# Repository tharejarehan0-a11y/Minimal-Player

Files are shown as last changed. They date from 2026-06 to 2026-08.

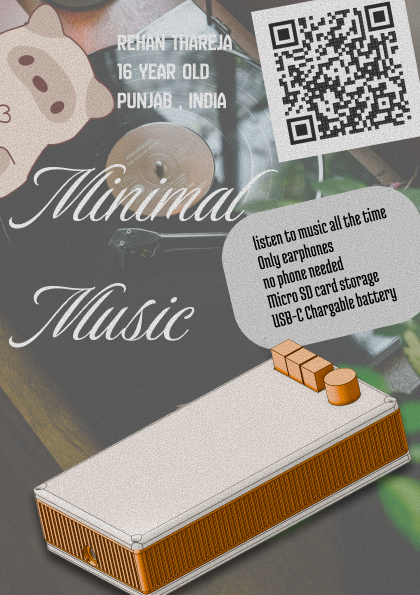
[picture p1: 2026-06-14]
A5 - 2.png

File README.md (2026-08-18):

# Minimal Player

**All the recordings are in JOURNAL.MD**

<p align="center">
A5 - 2
</p>
Minimal player is a device i can use to listen music in a compact way with only wired earphones offline and without worrying too much about the battery as it has a long battery life

---

## Why I Created This

The inspiration was from the need of having something i can carry everyday with me and listen music from with looking asthetic at the same times and some device with which i can use my wired earphones. But the thing is that i like to use such a device that gives only audio output through the audio jack bcz when you unplug it . It suddenly starts to play and doesnt stop i like that env where i can listen to music and no one disturbs me that is who i am and who i always will be . So i though why not create an Mp3 player where it has cool aesthetic design and also fulfills my requirements so i started with a simple pcb and then i came upon dac onto that and the battery mangagement we will talk more about that later . but for now i then did the routing and created the case the case was also quite complicated which we will cover on how to create that in aa nutshell in the next segment.

---

## How to create the MP3 schematics

I started by taking the raspberry pi pico cause it is the most easiest to work with microboard and also one of the most powerful ones also one more thing that attracted me about it was that it is micropython based which made the mechanics of code really easy for me to be done in the board itself. Then i came up with the decoupling of it and a switch for booting and stuff and then i stranded upon the micro sd slot the micro slot was a great option because it is one of the easiest to work with and works with the UART protocol which makes the wirinig also quite easy . Then i came upto the question okay i stored the data i have a microboard but what will i do of js the data the data also needs to play and what will play that that is the DAC and then i added the DAC to the MP3 Player which was quite complicated tho but still i added that and . It was a very difficult task to choose the right one for me , I Chose the PCM5102A for this and did stuff . I then continued to add the audio jack to it because the signals need to convert to sound somehow and i need my quite env after that i continued with working with the battery management and added the batter connector and the usb c for charging i also added the voltage regulator for stuff that requires 3.3v and 5v and handeled both separately and then i added some switches and lights for basic controls and also basic checks and then i chose to start with the rotatory encoders for more controls and then i switched to the pcb

---

## PCB

The pcb was quite complicated tho ngl I had to take care that the digital and analog signals do not interfare each other and also i have to take care of the thickness of the routing at different position due to the power management system itself and different power requiremwents here and there and then i went onto vias and stuff and it was quite a fast task tho 

---

## Case

Then i went onto the case and stuff . I wanted a quite aesthetic case tbh but at the same time I also wanted a case that fits my requirements like to be minimal and to signify that i am in my zone but still cool so i went with the orange and white color theme i know sounds a bit off but seems to fit my thingy and then what i did was i added little engravings at the sides of the case and added rotatory encoders to it i added two of them because i wanted to control the audio with one whereas the soong qeue with the other was quite a complicated task to add and make the cover for the rotatory encoders.

---

## Bill of Materials (BOM)

The table below lists all components used in the Minimal Player, matching the exact footprints and values from the KiCad PCB design layout. 

| Designator | Value | Footprint | Qty | India Sourcing / Purchase Links |
| :--- | :--- | :--- | :--- | :--- |
| **A1** | RaspberryPi_Pico | RaspberryPi_Pico_Common_THT | 1 | [Robu.in - Raspberry Pi Pico](https://robu.in/product/raspberry-pi-pico/) |
| **BT1** | Battery Connector | JST_PH_B2B-PH-K_1x02_P2.00mm_Vertical | 1 | [Robu.in - JST PH 2.0mm Male Header](https://robu.in/product/jst-ph-2-0-2-pin-male-connector-straight/) |
| **C1, C10, C11, C14, C15, C3** | $10\,\mu\text{F}$ | 0805 SMD Capacitor | 6 | [ElectronicsComp - 10uF 0805 Ceramic](https://www.electronicscomp.com/10uf-25v-0805-smd-capacitor) |
| **C12** | $2.2\text{ nF}$ | 0805 SMD Capacitor | 1 | [ElectronicsComp - 2.2nF 0805 Ceramic](https://www.electronicscomp.com/2.2nf-50v-0805-smd-capacitor) |
| **C13, R13** | 470 *(See Notes)* | 0805 SMD | 2 | [Resistor (470 $\Omega$)](https://www.electronicscomp.com/470-ohm-0805-smd-resistor) / [Capacitor (470 pF)](https://www.electronicscomp.com/470pf-50v-0805-smd-capacitor) |
| **C2, C5, C6, C8, C9** | $0.1\,\mu\text{F}$ | 0805 SMD Capacitor | 5 | [ElectronicsComp - 0.1uF 0805 Ceramic](https://www.electronicscomp.com/0.1uf-50v-0805-smd-capacitor) |
| **C4, C7** | $2.2\,\mu\text{F}$ | 0805 SMD Capacitor | 2 | [ElectronicsComp - 2.2uF 0805 Ceramic](https://www.electronicscomp.com/2.2uf-50v-0805-smd-capacitor) |
| **D1, D2** | LED_Small | 0805 SMD LED | 2 | [Robu.in - 0805 SMD LED Kit](https://robu.in/product/0805-smd-led-diode-assortment-kit-5-colors/) |
| **J1** | USB_C_Receptacle_14P | USB_C_Receptacle_HRO_TYPE-C-31-M-12 | 1 | [Robu.in - TYPE-C-31-M-12 Compatible 16P SMT](https://robu.in/product/usb-c-type-c-female-connector-16-pin-surface-mount/) |
| **J2** | Micro_SD_Card Slot | microSD_HC_Molex_104031-0811 | 1 | [ElectronicsComp - Push-Push MicroSD Slot](https://www.electronicscomp.com/micro-sd-card-slot-socket-smd-push-push-type) / [DigiKey India - Molex Exact](https://www.digikey.in/en/products/detail/molex/1040310811/3044122) |
| **J3** | AudioJack3 | Jack_3.5mm_CUI_SJ1-3523N_Horizontal | 1 | [DigiKey India - CUI SJ1-3523N Exact](https://www.digikey.in/en/products/detail/cui-devices/SJ1-3523N/738686) |
| **R1, R11, R2** | $5.1\text{ k}\Omega$ | 0805 SMD Resistor | 3 | [ElectronicsComp - 5.1k 0805 Resistor](https://www.electronicscomp.com/5.1k-ohm-0805-smd-resistor) |
| **R10** | $1.2\text{ k}\Omega$ | 0805 SMD Resistor | 1 | [ElectronicsComp - 1.2k 0805 Resistor](https://www.electronicscomp.com/1.2k-ohm-0805-smd-resistor) |
| **R12, R14, R5, R6, R7, R8, TH1** | $10\text{ k}\Omega$ *(See Notes)* | 0805 SMD | 7 | [Resistor (10k $\Omega$)](https://www.electronicscomp.com/10k-ohm-0805-smd-resistor) / [NTC Thermistor](https://www.electronicscomp.com/10k-ntc-thermistor-smd-0805) |
| **R3, R4** | $1\text{ k}\Omega$ | 0805 SMD Resistor | 2 | [ElectronicsComp - 1k 0805 Resistor](https://www.electronicscomp.com/1k-ohm-0805-smd-resistor) |
| **R9** | 0.4 / 400 $\Omega$ | 0805 SMD Resistor | 1 | [ElectronicsComp - 0805 SMD Resistor Assortment](https://www.electronicscomp.com/0805-smd-resistor-kit-36-values) |
| **SW1, SW2, SW3, SW4** | SW_SPST | SW_PUSH_6mm_H4.3mm | 4 | [Robu.in - 6x6x4.3mm Tactile Switch](https://robu.in/product/6x6x4-3mm-tactile-micro-push-button-switch-2-pin/) |
| **SW5** | RotaryEncoder | RotaryEncoder_Bourns_Vertical_PEC12R | 1 | [ElectronicsComp - EC11/12 with Switch](https://www.electronicscomp.com/ec11-rotary-encoder-with-switch-20mm-half-shaft) / [DigiKey India - Bourns Exact](https://www.digikey.in/en/products/detail/bourns-inc/PEC12R-4220F-S0024/3780188) |
| **U1** | TP4056-42-ESOP8 | SOIC-8-1EP (Exposed Thermal Pad) | 1 | [ElectronicsComp - TP4056 IC](https://www.electronicscomp.com/tp4056-linear-li-ion-battery-charger-ic) |
| **U2** | PCM5102A | TSSOP-20_4.4x6.5mm_P0.65mm | 1 | [ElectronicsComp - PCM5102A IC](https://www.electronicscomp.com/pcm5102a-audio-dac-ic-tssop-20) / [DigiKey India - TI Original](https://www.digikey.in/en/products/detail/texas-instruments/PCM5102APWR/3055979) |

---

# Schematics with Picture

Screenshot 2026-06-15 at 12 40 12 PM

The schematics were not that difficult because both the newer components had the datasheets to be followed the TP4056A and the PAM DAC they were easy to setup but the newer things that i explored onto this project were the electrolytic capcitors and how they have more capacitors and i also learned about this like analog and digital signals are different but sometimes when you have a project where you are going whith a pcb design for only 2 layers you can have same ground for both of them so i had the same ground for both of them and the TP4056 helped a lot with having a stable current towards the pico so that it can run easily and at last the PAM is a machine when it comes to audio only via headphones and works with the 3 pin audio jack that i setted up. I also added rotatory encoder , the buttons and a micro sd card a usb c and a lithium battery which can be recharged 

<br>

# PCB with picture
Screenshot 2026-06-15 at 12 54 30 PM

Then I started with the PCB it was really the hard part to deal with. I started by placing all the components but there were like so many capacitors and resistors that were to be placed which made it so confusing to set it up . So I took the schematics as the reference and placed all the capacitors as it was in that and then I started with routing it and got to know that the traces with the power are to be kept thick and the digital can be thin so i did it all wrong at the first try but got it on the second try. Then was the time to fix the errors . I had like so many errors I had to deal with so i started with the short errors all the way to body malformed errors and stuff and did that at last by filling the zone with AGND as the net 

<br>

# CAD with picture
Screenshot 2026-06-15 at 12 53 39 PM
Onshape is the best . I started by drawing two rectangles and then i extruded the part that was common to only one bigger rectangle in which with the same center was the other rectange and then i extruded it then i made the sketched for those tiny rectangular holes onto the sides of it and with the help of linear pattern i redrew them all easily and then i removed them from the sides to a certain extent to give a retro vibe then i imported the step file for the pcb and then what I did was i made the lower case and the upper case derived some parts and sketches drew the rotatory encoder the buttons . Imported the step files for the springs and the battery and then made the assembly that was it in all 
Onshape link : https://cad.onshape.com/documents/f82830b6c3d912c29ecf4908/w/00f5a3130b75aa3be964c3b3/e/6c625d5a5e73e1ecfabf8af3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

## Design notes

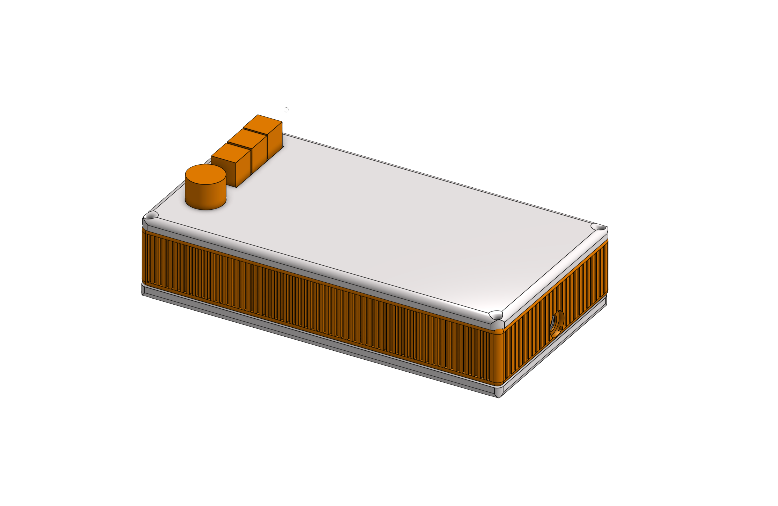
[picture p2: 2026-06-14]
Media/Untitled - 15 June 2026 at 00.29.48.png

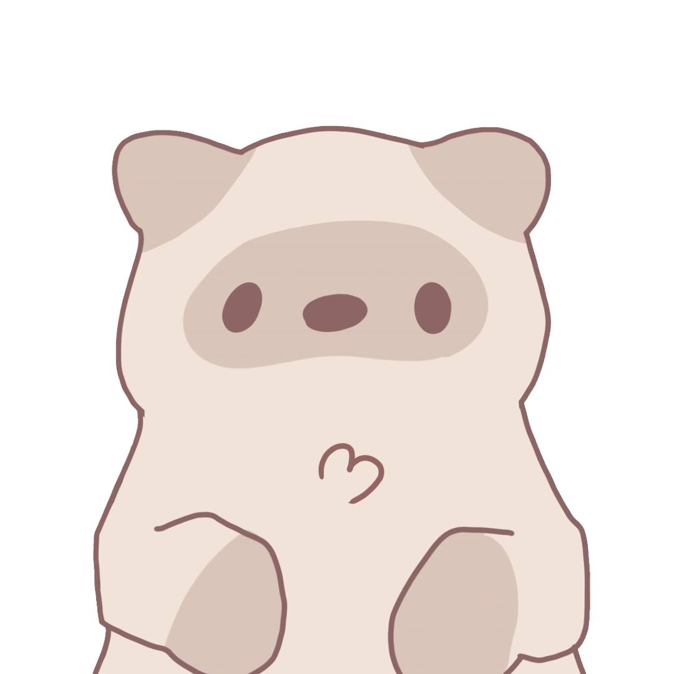
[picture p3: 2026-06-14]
Media/Untitled - 15 June 2026 at 01.00.05.png

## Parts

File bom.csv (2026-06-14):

Designator | Footprint | Quantity | Value | LCSC Part #
A1 | RaspberryPi_Pico_Common_THT | 1 | RaspberryPi_Pico
BT1 | JST_PH_B2B-PH-K_1x02_P2.00mm_Vertical | 1 | Battery
C1, C10, C11, C14, C15, C3 | 0805 | 6 | 10uf
C12 | 0805 | 1 | 2.2nf
C13, R13 | 0805 | 2 | 470
C2, C5, C6, C8, C9 | 0805 | 5 | 0.1uf
C4, C7 | 0805 | 2 | 2.2uf
D1, D2 | 0805 | 2 | LED_Small
J1 | USB_C_Receptacle_HRO_TYPE-C-31-M-12 | 1 | USB_C_Receptacle_USB2.0_14P
J2 | microSD_HC_Molex_104031-0811 | 1 | Micro_SD_Card
J3 | Jack_3.5mm_CUI_SJ1-3523N_Horizontal | 1 | AudioJack3
R1, R11, R2 | 0805 | 3 | 5.1k
R10 | 0805 | 1 | 1.2k
R12, R14, R5, R6, R7, R8, TH1 | 0805 | 7 | 10k
R3, R4 | 0805 | 2 | 1k
R9 | 0805 | 1 | 0.4
SW1, SW2, SW3, SW4 | SW_PUSH_6mm_H4.3mm | 4 | SW_SPST
SW5 | RotaryEncoder_Bourns_Vertical_PEC12R-3x17F-Nxxxx | 1 | RotaryEncoder
U1 | SOIC-8-1EP_3.9x4.9mm_P1.27mm_EP2.41x3.3mm_ThermalVias | 1 | TP4056-42-ESOP8
U2 | TSSOP-20_4.4x6.5mm_P0.65mm | 1 | PCM5102A

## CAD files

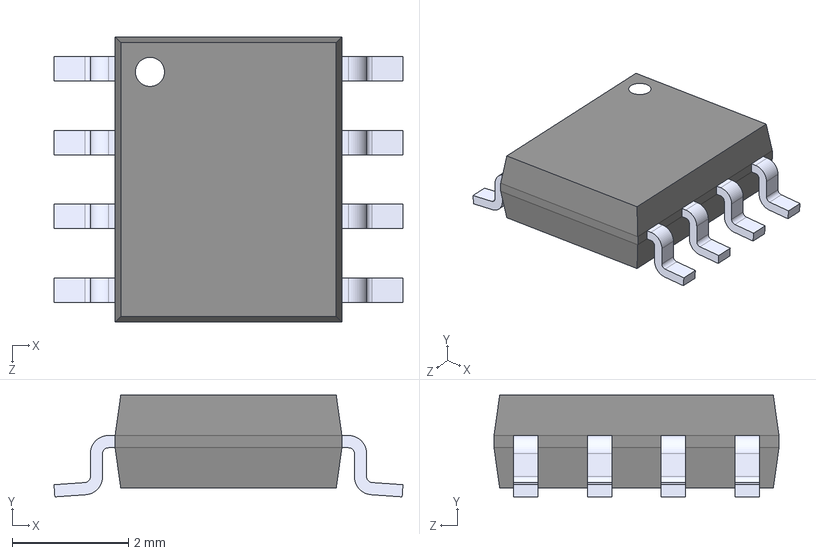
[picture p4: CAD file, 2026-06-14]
3d_models/TP4056-42-ESOP8--3DModel-STEP-56544.STEP
6.00 x 1.75 x 4.90 mm

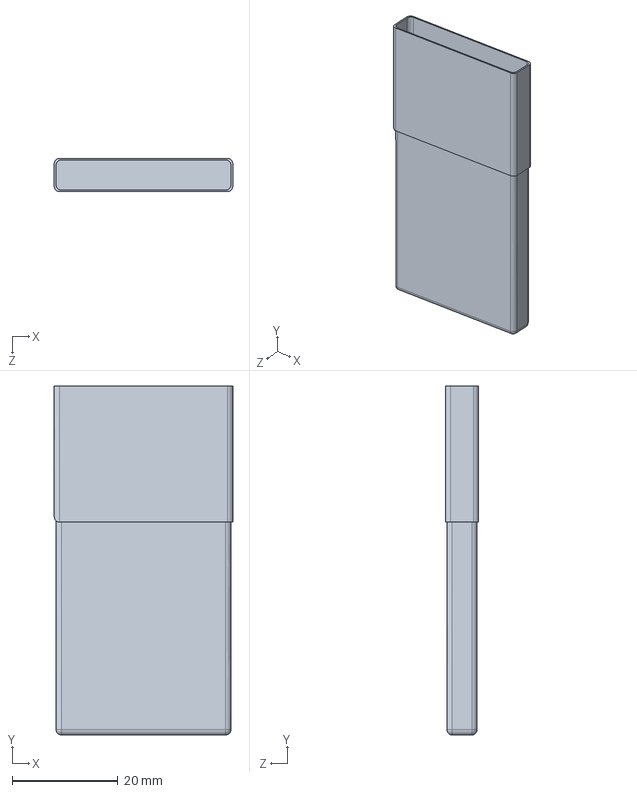
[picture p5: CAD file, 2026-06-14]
3d_models/battery.SLDPRT
33.7 x 65.8 x 6.29 mm

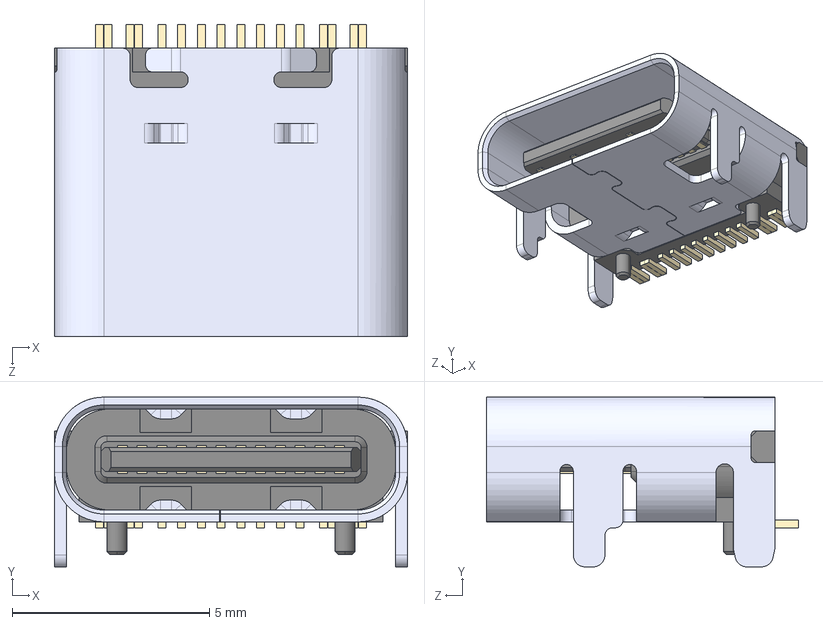
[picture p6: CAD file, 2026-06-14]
3d_models/TYPE-C-31-M-12--3DModel-STEP-56544.STEP
8.94 x 4.30 x 7.90 mm

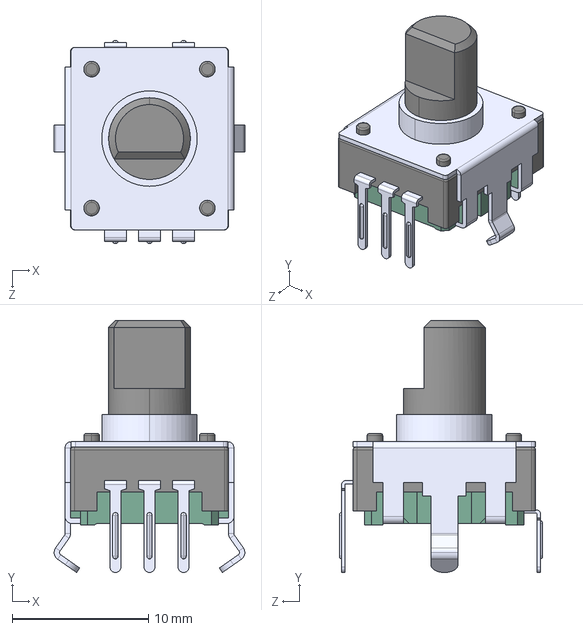
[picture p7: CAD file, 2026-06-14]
3d_models/PEC12R-4115F-S0012--3DModel-STEP-510211.STEP
14.0 x 18.5 x 14.9 mm

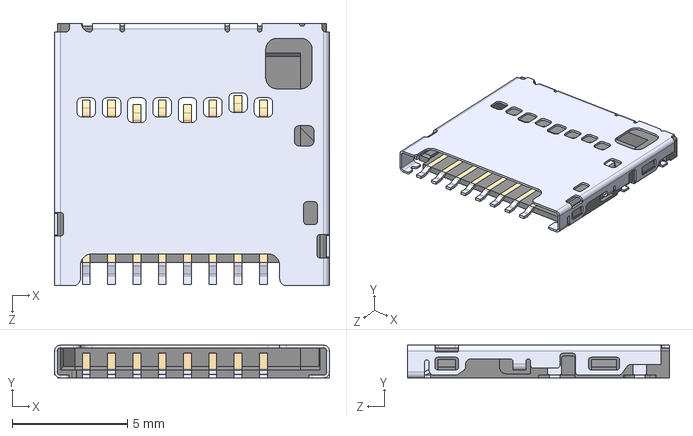
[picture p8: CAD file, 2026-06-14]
3d_models/104031-0811--3DModel-STEP-269445.STEP
12.0 x 1.42 x 11.4 mm

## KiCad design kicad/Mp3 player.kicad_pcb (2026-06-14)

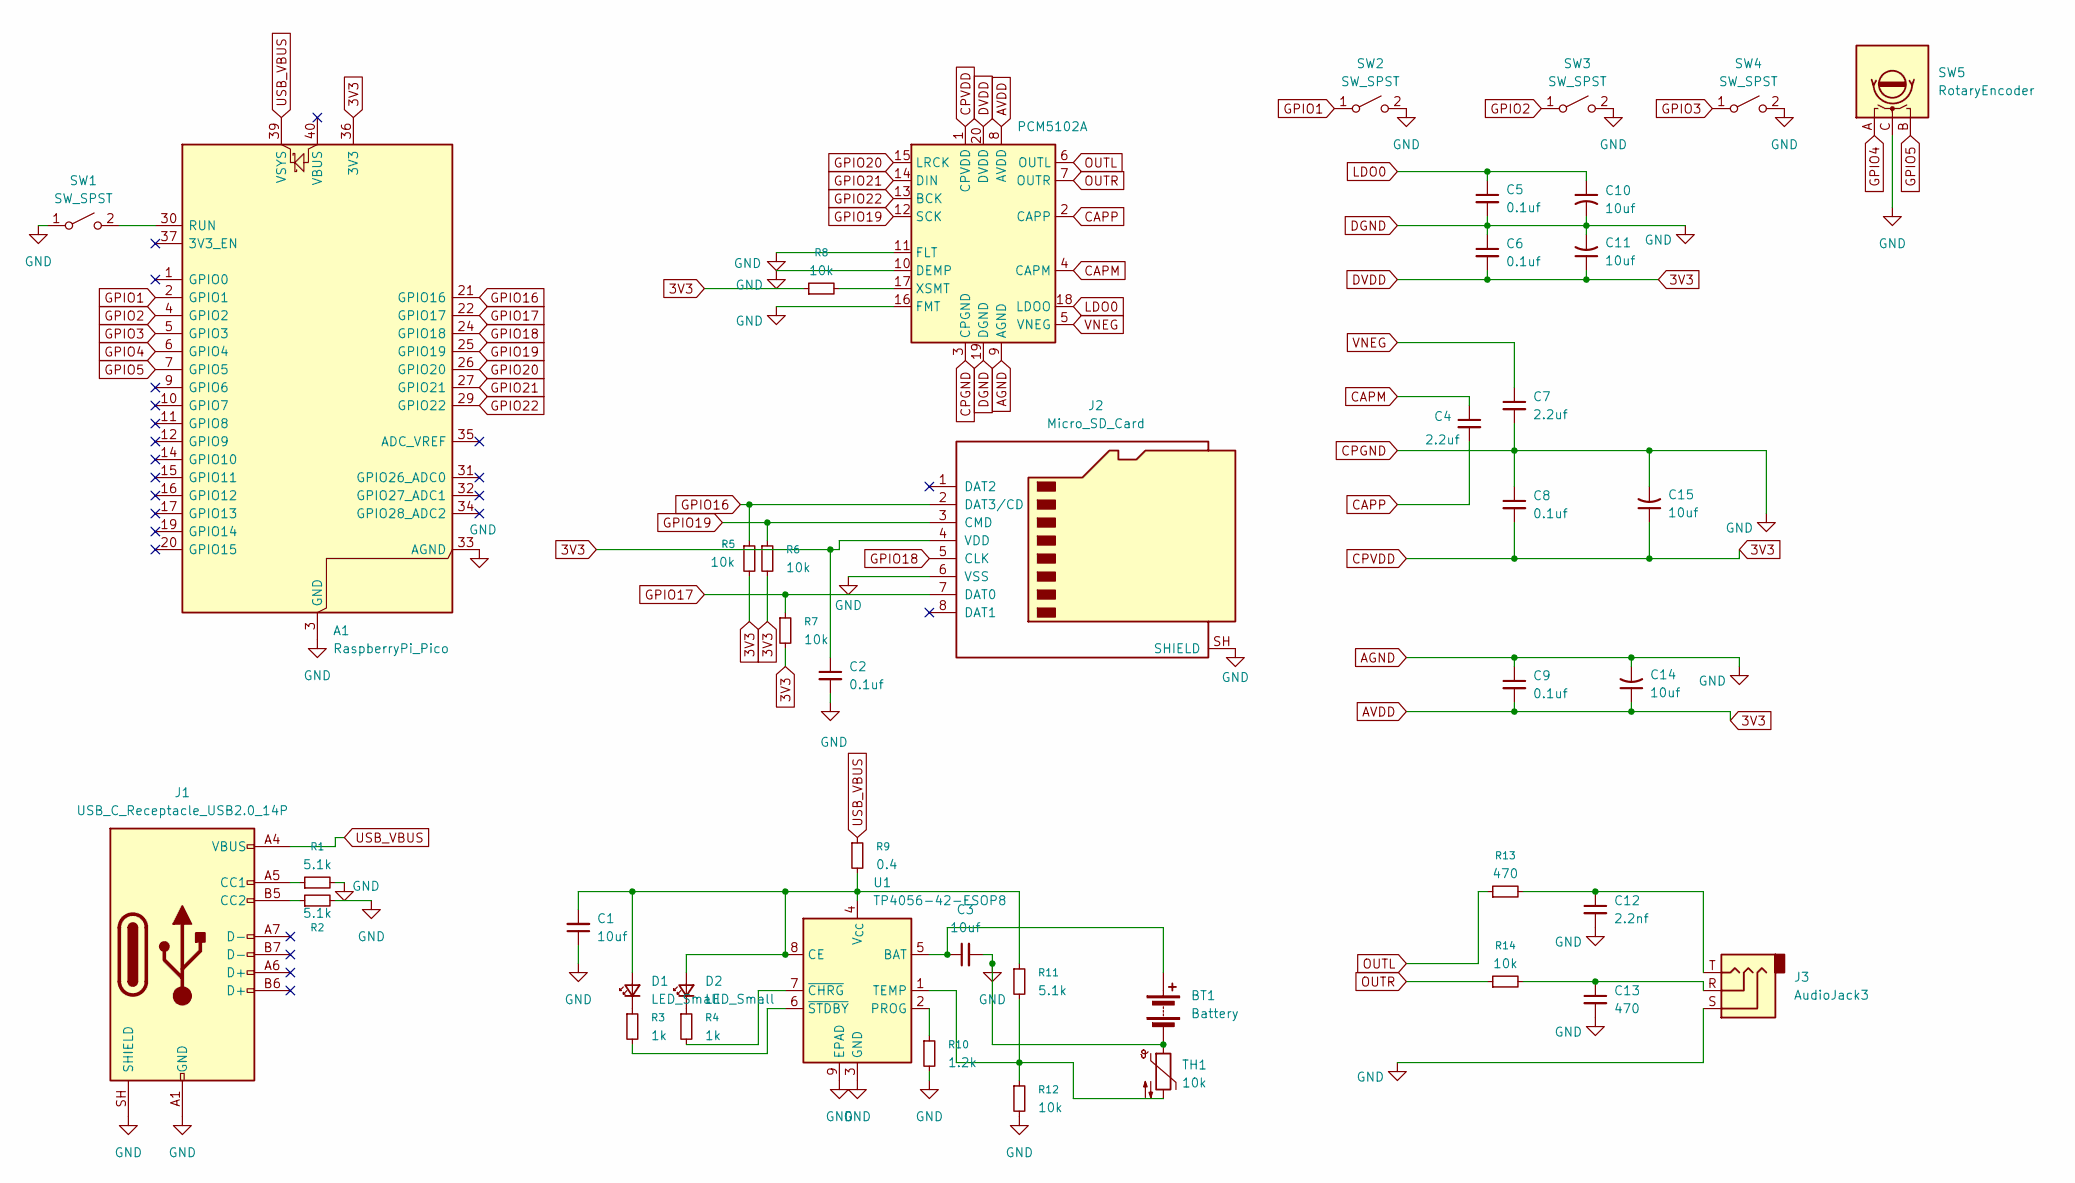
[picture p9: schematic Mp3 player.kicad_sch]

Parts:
A1: RaspberryPi_Pico; RaspberryPi_Pico_Common_THT
BT1: Battery; JST_PH_B2B-PH-K_1x02_P2.00mm_Vertical
C1, C3, C10, C11, C14, C15: 10uf; C_0805_2012Metric
C2, C5, C6, C8, C9: 0.1uf; C_0805_2012Metric
C4, C7: 2.2uf; C_0805_2012Metric
C12: 2.2nf; C_0805_2012Metric_Pad1.18x1.45mm_HandSolder
C13: 470; R_0805_2012Metric
D1, D2: LED_Small; LED_0805_2012Metric
J1: USB_C_Receptacle_USB2.0_14P; USB_C_Receptacle_HRO_TYPE-C-31-M-12
J2: Micro_SD_Card; microSD_HC_Molex_104031-0811
J3: AudioJack3; Jack_3.5mm_CUI_SJ1-3523N_Horizontal
R1, R2, R11: 5.1k; R_0805_2012Metric
R3, R4: 1k; R_0805_2012Metric
R5, R6, R7, R8, R12, R14: 10k; R_0805_2012Metric
R9: 0.4; R_0805_2012Metric
R10: 1.2k; R_0805_2012Metric
R13: 470; R_0805_2012Metric
SW1, SW2, SW3, SW4: SW_SPST; SW_PUSH_6mm_H4.3mm
SW5: RotaryEncoder; RotaryEncoder_Bourns_Vertical_PEC12R-3x17F-Nxxxx
TH1: 10k; R_0805_2012Metric
U1: TP4056-42-ESOP8; SOIC-8-1EP_3.9x4.9mm_P1.27mm_EP2.41x3.3mm_ThermalVias
U2: PCM5102A; TSSOP-20_4.4x6.5mm_P0.65mm

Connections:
3V3: A1.36 (3V3), C2.1, C6.2, C8.2, C9.2, C11.1, C14.1, C15.1, J2.4 (VDD), R5.2, R6.2, R7.2, R8.1, U2.1 (CPVDD), U2.8 (AVDD), U2.20 (DVDD)
AGND: A1.3 (GND), A1.8 (GND), A1.13 (GND), A1.18 (GND), A1.23 (GND), A1.28 (GND), A1.33 (AGND), A1.38 (GND), BT1.2 (-), C1.1, C2.2, C3.2, C5.2, C6.1, C7.2, C8.1, C9.1, C10.2, C11.2, C12.2, C13.2, C14.2, C15.2, J1.A1 (GND), J1.A12 (GND), J1.B1 (GND), J1.B12 (GND), J1.SH (SHIELD), J2.6 (VSS), J2.SH (SHIELD), J3.S, R1.2, R2.2, R10.2, R12.2, SW1.1 (A), SW2.2 (B), SW3.2 (B), SW4.2 (B), SW5.C, TH1.1, U1.3 (GND), U1.9 (EPAD), U2.3 (CPGND), U2.9 (AGND), U2.10 (DEMP), U2.11 (FLT), U2.16 (FMT), U2.19 (DGND)
CAPM: C4.1, U2.4 (CAPM)
CAPP: C4.2, U2.2 (CAPP)
GPIO1: A1.2 (GPIO1), SW2.1 (A)
GPIO2: A1.4 (GPIO2), SW3.1 (A)
GPIO3: A1.5 (GPIO3), SW4.1 (A)
GPIO4: A1.6 (GPIO4), SW5.A
GPIO5: A1.7 (GPIO5), SW5.B
GPIO16: A1.21 (GPIO16), J2.2 (DAT3/CD), R5.1
GPIO17: A1.22 (GPIO17), J2.7 (DAT0), R7.1
GPIO18: A1.24 (GPIO18), J2.5 (CLK)
GPIO19: A1.25 (GPIO19), J2.3 (CMD), R6.1, U2.12 (SCK)
GPIO20: A1.26 (GPIO20), U2.15 (LRCK)
GPIO21: A1.27 (GPIO21), U2.14 (DIN)
GPIO22: A1.29 (GPIO22), U2.13 (BCK)
LDO0: C5.1, C10.1, U2.18 (LDOO)
unnamed: A1.30 (RUN), SW1.2 (B)
unnamed: BT1.1 (+), C3.1, U1.5 (BAT)
unnamed: C12.1, J3.T, R13.2
unnamed: C13.1, J3.R, R14.2
unnamed: C1.2, D1.2 (A), D2.2 (A), R9.2, R11.1, U1.4 (V_{CC}), U1.8 (CE)
unnamed: D1.1 (K), R3.1
unnamed: D2.1 (K), R4.1
unnamed: J1.A5 (CC1), R1.1
unnamed: J1.B5 (CC2), R2.1
unnamed: R10.1, U1.2 (PROG)
unnamed: R11.2, R12.1, TH1.2, U1.1 (TEMP)
unnamed: R4.2, U1.7 (~CHRG)
unnamed: R3.2, U1.6 (~STDBY)
unnamed: R8.2, U2.17 (XSMT)
OUTL: R13.1, U2.6 (OUTL)
OUTR: R14.1, U2.7 (OUTR)
USB_VBUS: A1.39 (VSYS), J1.A4 (VBUS), J1.A9 (VBUS), J1.B4 (VBUS), J1.B9 (VBUS), R9.1
VNEG: C7.1, U2.5 (VNEG)

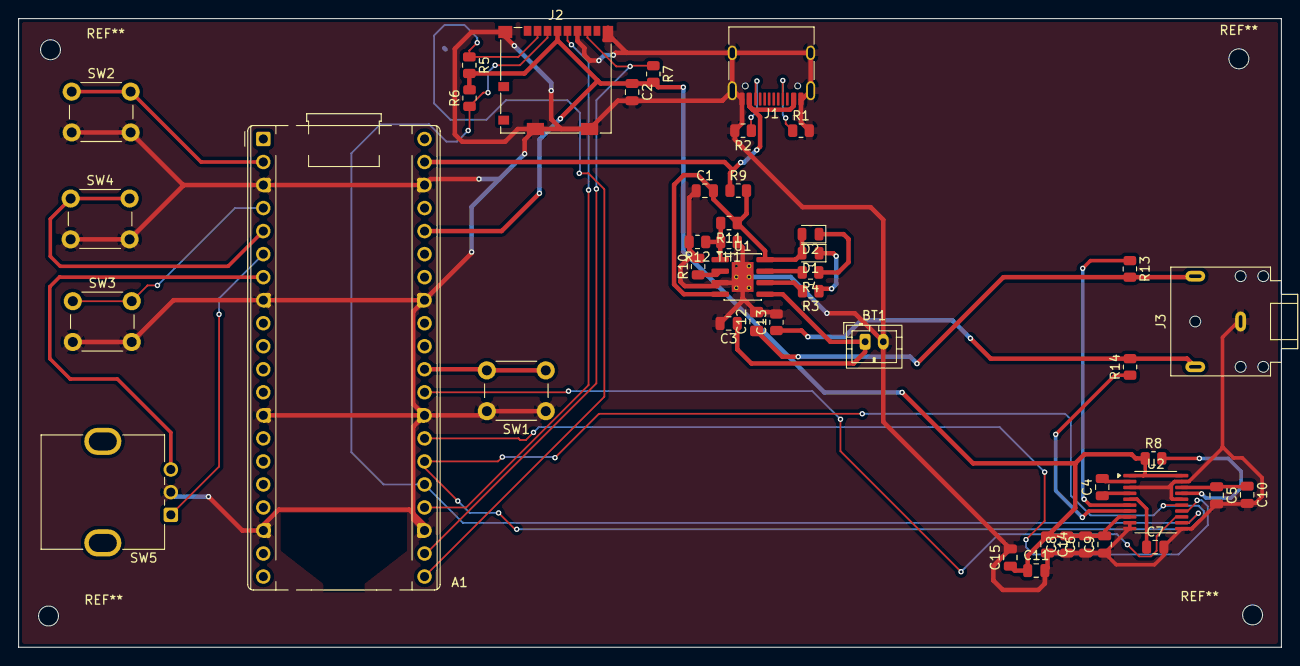
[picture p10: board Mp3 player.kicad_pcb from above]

Board: 2 copper layers, 139.3 x 69.3 mm, 44 parts (0 on the bottom side), 35 nets.

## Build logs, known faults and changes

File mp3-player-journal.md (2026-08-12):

# MP3 Player — Journal Export

- Exported at: 2026-08-12T11:07:08Z
- Project ID: 4535
- Entries: 9

## Entry 1
- ID: 13714
- Author: Rehan
- Created At: 2026-06-13T13:08:59Z

### Content

# MP3 Player
In this you can cut like 50 mins i wasted them really idk no why . I am really really sorry for that waste of time I apologize for that . In i did near about all the schematics js left with the dac and the amplifier and the display other all components i added in this now 
Screenshot 2026-06-13 at 6.38.48 PM.png

### Recording Links

- https://lookout.hackclub.com/api/media/1630f05e-cc41-481d-9190-fe8418885256/video.mp4

## Entry 2
- ID: 13859
- Author: Rehan
- Created At: 2026-06-14T02:41:07Z

### Content

# Previous Recordings
These are the previous recordings i did for the research of this project and after all this i ended up with something like this and now its not that difficult
Screenshot 2026-06-14 at 7.04.47 AM.png

### Recording Links

- https://lookout.hackclub.com/api/media/4760cf3d-70cf-43dd-a9f4-acd17364e7c6/video.mp4
- https://lookout.hackclub.com/api/media/50664aba-24ed-40f2-8eeb-7b7011e7490e/video.mp4
- https://lookout.hackclub.com/api/media/74d6a397-c9a7-4ea9-999c-3c8ee02ff81b/video.mp4
- https://lookout.hackclub.com/api/media/8a7e227c-71ce-4d19-a7ec-814f20774916/video.mp4
- https://lookout.hackclub.com/api/media/5ecfc95c-5713-4510-aabd-cd4b8d16a649/video.mp4
- https://lookout.hackclub.com/api/media/6cb5d88e-118d-48d9-b644-5b6e4be64185/video.mp4
- https://lookout.hackclub.com/api/media/a9c9b66d-930b-40c4-b02e-bbcef5e3dbec/video.mp4
- https://lookout.hackclub.com/api/media/c3d4ac4d-ec66-4f57-a3e7-d6a4dc8e7d33/video.mp4
- https://lookout.hackclub.com/api/media/9c76bf49-be0a-4c82-9bf7-db9e38700728/video.mp4

## Entry 3
- ID: 13860
- Author: Rehan
- Created At: 2026-06-14T02:43:58Z

### Content

# The right schematics
In this I have done the schematics of mp3 player after all component pondering and research i found the right components and the right datsheets and the second recording is for the troubleshooting and component changing a lil bit
Screenshot 2026-06-14 at 8.13.21 AM.png

### Recording Links

- https://lookout.hackclub.com/api/media/44fdff23-45e0-40fc-b570-09c235a48f1f/video.mp4
- https://lookout.hackclub.com/api/media/9bf5b075-98aa-4dd8-83b0-b7bf72485e0e/video.mp4

## Entry 4
- ID: 13908
- Author: Rehan
- Created At: 2026-06-14T07:16:30Z

### Content

# Done placing the components
I did the schematics now i have place all the footprints on to the pcb and assigned all the components 
Screenshot 2026-06-14 at 12.46.17 PM.png

### Recording Links

- https://lookout.hackclub.com/api/media/add86276-7fc4-49b7-90e5-440a2a2eb35f/video.mp4

## Entry 5
- ID: 13922
- Author: Rehan
- Created At: 2026-06-14T09:01:18Z

### Content

# PCB Routing Completed
Did with Routing the pcb and now in the next i will js troubleshoot everything
Screenshot 2026-06-14 at 2.31.05 PM.png

### Recording Links

- https://lookout.hackclub.com/api/media/d7385bae-6715-4871-be44-e3c3c3e1919f/video.mp4

## Entry 6
- ID: 13966
- Author: Rehan
- Created At: 2026-06-14T13:07:29Z

### Content

# Sides
Made the sides of the case and a hole for the audio jack in onshape and also added some styling on the sides to with the linear pattern

Screenshot 2026-06-14 at 6.37.16 PM.png

### Recording Links

- https://lookout.hackclub.com/api/media/f430129c-f75a-4836-98fa-f35cca8f9ae8/video.mp4

## Entry 7
- ID: 14000
- Author: Rehan
- Created At: 2026-06-14T15:25:02Z

### Content

# Case Completed 
I js completed the case for the mp3 player and added the holes the holes for the pcb and the buttons are still left and the battery 3d model is still left idk if i will find one
Screenshot 2026-06-14 at 8.54.53 PM.png

### Recording Links

- https://lookout.hackclub.com/api/media/069aeebb-93ef-4434-94f4-69014d9b3c10/video.mp4

## Entry 8
- ID: 14078
- Author: Rehan
- Created At: 2026-06-14T19:43:42Z

### Content

# CAD
Did the pcb and and at last did the cad also and added all the buttons needed and and rotatory encoders needed made the zine also
A5 - 2.png

### Recording Links

- https://lookout.hackclub.com/api/media/34406a64-8fff-46c0-9aa8-606240f24b0f/video.mp4

## Entry 9
- ID: 14189
- Author: Rehan
- Created At: 2026-06-15T07:40:55Z

### Content

# Organised the repo
I organised the repo added the production files and also added the firmware and the link to the onshape assembly in the readme and the bom also was added 
Screenshot 2026-06-15 at 1.10.45 PM.png

### Recording Links

- https://lookout.hackclub.com/api/media/855b5e2e-4de3-4017-8949-ed1cd4d5a552/video.mp4

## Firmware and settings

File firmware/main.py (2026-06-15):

import os
from machine import Pin, SPI, I2S
import sdcard
import time

# --- 1. PIN CONFIGURATION ---
# Rotary Encoder Pins
ENCODER_A = Pin(2, Pin.IN, Pin.PULL_UP)
ENCODER_B = Pin(3, Pin.IN, Pin.PULL_UP)
BUTTON_PIN = Pin(4, Pin.IN, Pin.PULL_UP)

# MicroSD Card SPI Pins
SD_CS = Pin(5, Pin.OUT)
spi = SPI(0, sck=Pin(6), mosi=Pin(7), miso=Pin(4)) # Adjust to your exact SPI pins

# PCM5102A I2S Pins
I2S_BCK = Pin(16)  # Bit Clock
I2S_LRCK = Pin(17) # Left/Right Clock (Word Select)
I2S_DIN = Pin(18)  # Data In

# --- 2. HARDWARE INITIALIZATION ---
# Mount the SD Card
try:
    sd = sdcard.SDCard(spi, SD_CS)
    os.mount(sd, "/sd")
    print("SD Card mounted successfully!")
except Exception as e:
    print("SD Card setup failed:", e)

# Initialize I2S Audio Audio Output
audio_out = I2S(
    0, 
    sck=I2S_BCK, 
    ws=I2S_LRCK, 
    sd=I2S_DIN, 
    mode=I2S.TX, 
    bits=16, 
    format=I2S.STEREO, 
    rate=44100, 
    ibuf=4096
)

# --- 3. ENCODER & PLAYER VARIABLES ---
volume = 50  # Start at 50% volume
last_state_A = ENCODER_A.value()
playing = True

# --- 4. CORE FUNCTIONS ---
def handle_encoder():
    global last_state_A, volume
    current_state_A = ENCODER_A.value()
    
    # Check if knob turned
    if current_state_A != last_state_A and current_state_A == 0:
        if ENCODER_B.value() != current_state_A:
            volume = min(100, volume + 5) # Turn Right: Vol Up
            print(f"Volume: {volume}%")
        else:
            volume = max(0, volume - 5)  # Turn Left: Vol Down
            print(f"Volume: {volume}%")
            
    last_state_A = current_state_A

def play_wav(filename):
    global playing
    try:
        with open(filename, "rb") as wav:
            # Skip the 44-byte WAV header to get straight to raw audio data
            wav.seek(44) 
            
            # Create a memory buffer for fast reading
            buffer = bytearray(1024)
            
            while True:
                # Check controls while playing
                handle_encoder()
                if BUTTON_PIN.value() == 0:  # Button pressed
                    playing = not playing
                    print("Play/Pause Toggled")
                    time.sleep(0.3)  # Software debounce delay
                
                if playing:
                    num_bytes = wav.readinto(buffer)
                    if num_bytes == 0:
                        break # End of file reached
                    
                    # Write audio chunk to the I2S DAC
                    audio_out.write(buffer[:num_bytes])
                    
    except Exception as e:
        print("Playback error:", e)

# --- 5. MAIN LOOP ---
print("Scanning SD Card for music...")
songs = [f"/sd/{file}" for file in os.listdir("/sd") if file.endswith(".wav")]

if songs:
    print(f"Found tracks: {songs}")
    while True:
        for song in songs:
            print(f"Playing: {song}")
            play_wav(song)
else:
    print("No .wav files found on the SD card root directory.")

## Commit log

2026-06-14 Enhance README with project details and specifications
    Expanded the README to include details about the Minimal Player's purpose, inspiration, bill of materials, and hardware features.
2026-06-14 upload of all the components
    [104031-0811--3DModel-STEP-269445.STEP, Mp3 player.kicad_pcb, Mp3 player.kicad_sch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]
2026-06-14 did with the req
    [bom.csv, designators.csv, positions.csv]
2026-06-15 Enhance README with project details and images
    Expanded the README with detailed sections on schematics, PCB design, and CAD process, including images and explanations of the components used and challenges faced.
2026-06-15 Revise BOM with detailed component information
    Updated the Bill of Materials (BOM) section with detailed component references, descriptions, quantities, and purchase links.
2026-06-15 Update CAD section with project details and link
    Added Onshape link and expanded CAD project description.
2026-06-24 Update Raspberry Pi Pico sourcing links in README
    Removed one of the purchase links for Raspberry Pi Pico.
2026-08-12 Enhance README with detailed project insights
    Expanded the 'Why I Created This' section with detailed motivations and design choices for the MP3 player. Added new sections on schematics, PCB design, and CAD process, including images and explanat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
